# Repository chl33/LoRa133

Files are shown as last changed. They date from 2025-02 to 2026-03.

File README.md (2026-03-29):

# LoRa133

This project is a base station for LoRa-based satellite sensor devices such as [Garden133](https://github.com/chl33/Garden133).  It includes KiCAD board design and C++ firmware.  LoRa133 allows satellite sensor units to communicate using LoRa radio modules and automatically integrate with Home Assistant.  I build the firmware using the [Platformio](https://platformio.org/) build system.

This is a picture of the base station in its project box in [`OpenSCAD/Lora133/`](OpenSCAD/Lora133/).

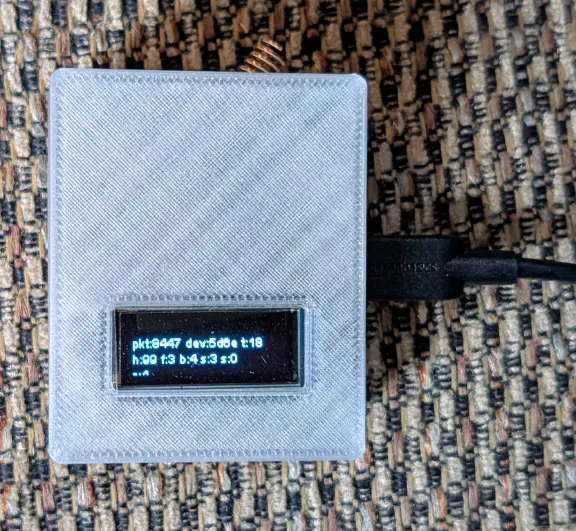
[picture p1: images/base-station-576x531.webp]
Base station


This is the PCBA documented in [`KiCAD/LoRa133/`](KiCAD/LoRa133/).

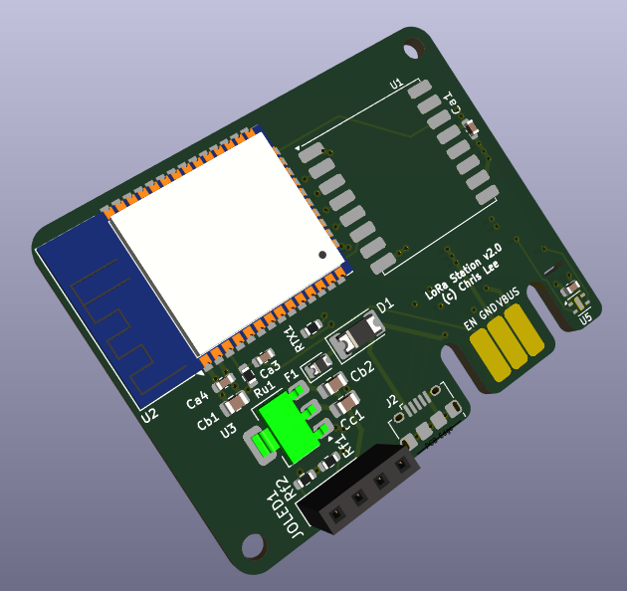
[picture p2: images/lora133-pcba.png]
LoRa133 PCBA


Here is what the web interface (written in Svelte) looks like:

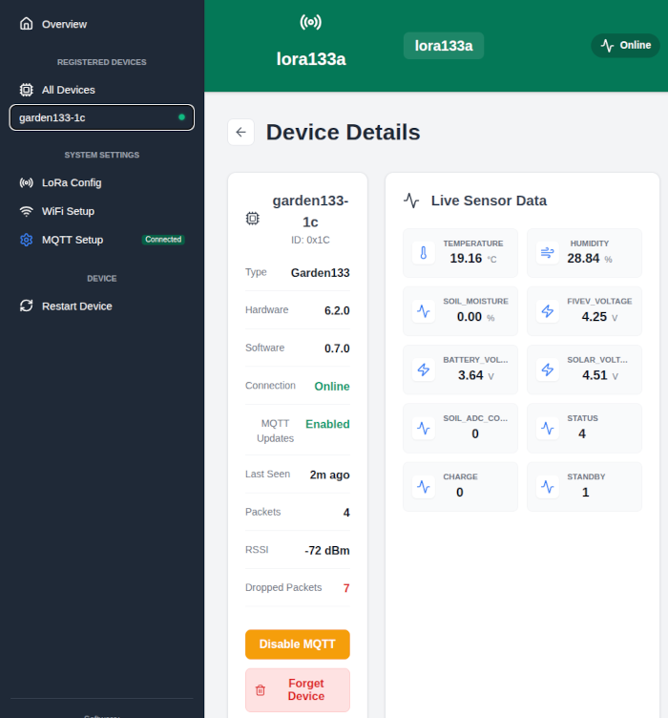
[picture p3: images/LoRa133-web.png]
LoRa133 Web UI


Please see the [Introducing Garden133](https://selectiveappeal.org/posts/garden133/) blog post for more information.

This device uses these libraries:
- [og3](https://github.com/chl33/og3). A basic C++ library for esp development in the Arduino environment.
- [og3x-lora](https://github.com/chl33/og3x-lora). LoRa module support for the og3 library.
- [og3x-satellite](https://github.com/chl33/og3x-satellite). A library that helps build a satellite architecture of a base station and satellite sensors.

## What's New in v0.7.0

*   **Satellite Device Memory**: The bridge now persists its satellite network knowledge across reboots. Restarts no longer result in a blank device list.
*   **Enhanced Visibility**: Real-time RSSI, packet counts, and human-readable "Last Seen" timers added to the web dashboard.
*   **Mobile Optimized**: Fully responsive web interface that fits perfectly on smartphone screens.
*   **og3 v0.6.1 Core**: Modernized backend leveraging the latest declarative dependency and file storage improvements.

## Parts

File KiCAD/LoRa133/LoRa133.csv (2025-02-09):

Source: | /home/chris/KiCad/GardenLee/GardenLee.kicad_sch
Date: | Sat 08 Oct 2022 03:04:13 PM EDT
Tool: | Eeschema 6.0.8-f2edbf62ab~116~ubuntu20.04.1
Generator: | /usr/share/kicad/plugins/bom_csv_grouped_by_value_with_fp.py
Component Count: | 24
Ref | Qnty | Value | Cmp name | Footprint | Description | Vendor
C_3V3_1, | 1 | 100nF | C | Capacitor_SMD:C_0603_1608Metric | Unpolarized capacitor
C_3V3_2, | 1 | 10uF | C | Capacitor_SMD:C_0805_2012Metric | Unpolarized capacitor
C_RST1, | 1 | 100nF | C | Capacitor_SMD:C_0603_1608Metric | Unpolarized capacitor
C_SMTC1, | 1 | 100nF | C | Capacitor_SMD:C_0603_1608Metric | Unpolarized capacitor
CEN1, | 1 | 1uF | C | Capacitor_SMD:C_0603_1608Metric | Unpolarized capacitor
CPI1, | 1 | 10uF | C | Capacitor_SMD:C_0603_1608Metric | Unpolarized capacitor
CPO1, | 1 | 47uF | C | Capacitor_SMD:C_0603_1608Metric | Unpolarized capacitor
DUSB1, | 1 | SS14 | 1N5819 | Diode_SMD:D_2010_5025Metric | 40V 1A Schottky Barrier Rectifier Diode, DO-41
F1, | 1 | 0.5A | Fuse_Small | Diode_SMD:D_0805_2012Metric | Fuse, small symbol
J1, | 1 | USB_B_Micro | USB_B_Micro | Library:USB-micro-aliexpress | USB Micro Type B connector
JCOM1, | 1 | Conn_01x04 | Conn_01x04 | Connector_PinHeader_2.54mm:PinHeader_1x04_P2.54mm_Vertical | Generic connector, single row, 01x04, script generated (kicad-library-utils/schlib/autogen/connector/)
JP1, | 1 | SolderJumper_2_Open | SolderJumper_2_Open | Jumper:SolderJumper-2_P1.3mm_Open_Pad1.0x1.5mm | Solder Jumper, 2-pole, open
Q1, | 1 | UMH3N | UMH3N | Package_TO_SOT_SMD:SOT-363_SC-70-6 | 0.1A Ic, 50V Vce, Dual NPN Input Resistor Transistors, SOT-363
R_IO_1, | 1 | 470 | R | Resistor_SMD:R_0603_1608Metric | Resistor
R_RIO1, | 1 | 12k | R | Resistor_SMD:R_0603_1608Metric | Resistor
REN1, | 1 | 10k | R | Resistor_SMD:R_0603_1608Metric | Resistor
RRX1, | 1 | 470 | R | Resistor_SMD:R_0603_1608Metric | Resistor
RTX1, | 1 | 470 | R | Resistor_SMD:R_0603_1608Metric | Resistor
SW1, | 1 | PTS841 | PTS841 | Library:PTS841
U1, | 1 | RFM95W-915S2 | RFM95W-915S2 | RF_Module:HOPERF_RFM9XW_SMD | Low power long range transceiver module, SPI and parallel interface, 915 MHz, spreading factor 6 to12, bandwith 7.8 to 500kHz, -111 to -148 dBm, SMD-16, DIP-16
U2, | 1 | ESP32-WROOM-32 | ESP32-WROOM-32 | RF_Module:ESP32-WROOM-32 | RF Module, ESP32-D0WDQ6 SoC, Wi-Fi 802.11b/g/n, Bluetooth, BLE, 32-bit, 2.7-3.6V, onboard antenna, SMD
U3, | 1 | AMS1117-3.3 | AMS1117-3.3 | Package_TO_SOT_SMD:SOT-223-3_TabPin2 | 1A Low Dropout regulator, positive, 3.3V fixed output, SOT-223
U4, | 1 | CH340C | CH340C | Package_SO:SOIC-16_3.9x9.9mm_P1.27mm | USB serial converter, UART, SOIC-16
U5, | 1 | SHTC3 | SHTC3 | Sensor_Humidity:Sensirion_DFN-4-1EP_2x2mm_P1mm_EP0.7x1.6mm | Humidity and Temperature Sensor, +/-2%RH, +/-0.2degC, I2C, 1.62-3.6V, DFN-4

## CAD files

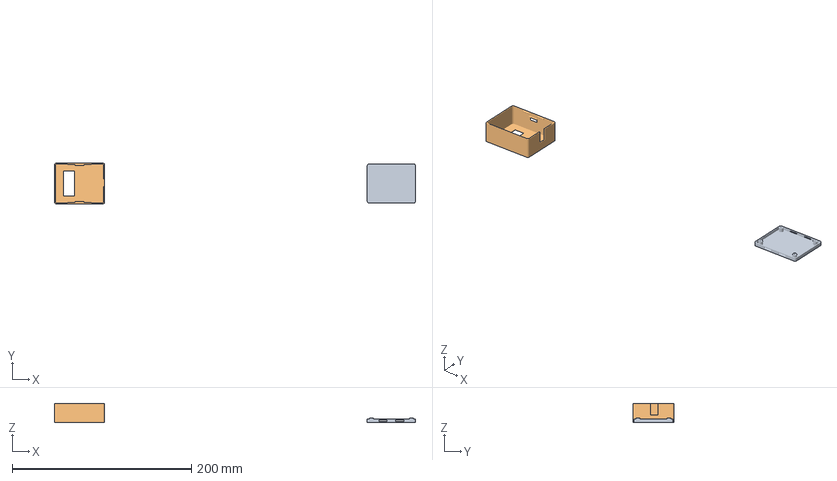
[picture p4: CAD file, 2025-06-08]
OpenSCAD/Lora133/LoRa133.3mf
402.9 x 45.8 x 21.5 mm
box_bottom.stl
box_top.stl

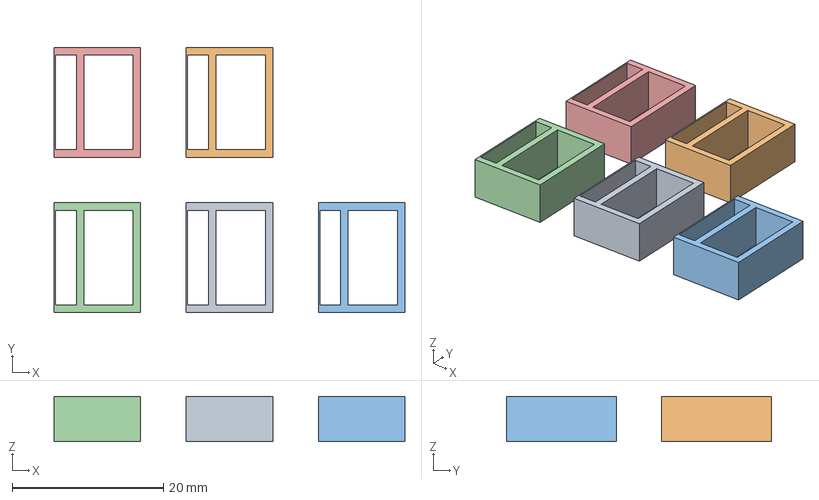
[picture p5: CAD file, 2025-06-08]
OpenSCAD/OLEDSupport/OLEDSupport.3mf
46.4 x 35.0 x 6.00 mm

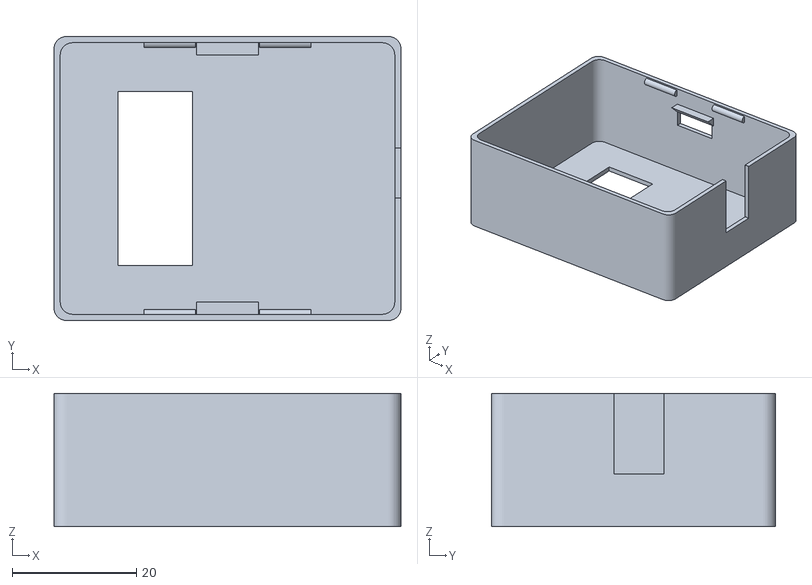
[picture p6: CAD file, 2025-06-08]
OpenSCAD/Lora133/box_top.stl
55.9 x 45.8 x 21.5

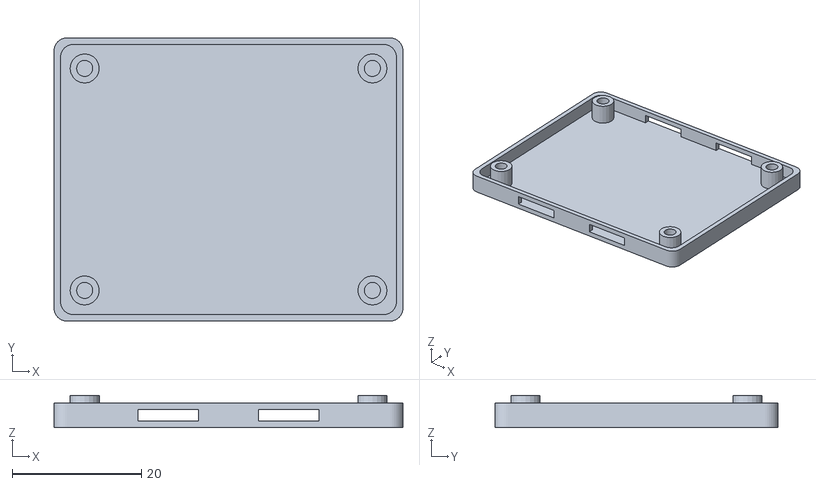
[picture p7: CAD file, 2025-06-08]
OpenSCAD/Lora133/box_bottom.stl
53.9 x 43.8 x 5.01

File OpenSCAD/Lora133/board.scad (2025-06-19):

// Copyright (c) 2025 Chris Lee and contibuters.
// Licensed under the MIT license. See LICENSE file in the project root for details.

include <ProjectBox/project_box.scad>
include <ProjectBox/oled91.scad>

board_thickness = 1.6;
pad_space = 2.54;
// GardenL33: board_dims = [26*pad_space, 15.5*pad_space, board_thickness];
board_dims = [19.5*pad_space, 15.5*pad_space, board_thickness];

module LoRa133_to_oled_frame(z_translate=true) {
  u = pad_space;
  z_offset = z_translate ? 13 : 0;
  translate([u*3-0.5, 0.6, z_offset]) children();
}

module Lora133_board() {
  u = pad_space;

  // Board imported from KiCad (VRML) -> meshlab
   translate([board_dims[0]/2, board_dims[1]/2, board_dims[2]/2]) color("white")
    import(file="LoRa133.stl", convexity=3);

  LoRa133_to_oled_frame() oled91();
}

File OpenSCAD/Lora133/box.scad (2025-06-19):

// Copyright (c) 2025 Chris Lee and contibuters.
// Licensed under the MIT license. See LICENSE file in the project root for details.

include <ProjectBox/project_box.scad>
include <ProjectBox/mounts.scad>
include <board.scad>

ones = [1, 1, 1];

wall_thickness = 1;
gap = 0.2;
corner_radius = 2;
mount_offset = pad_space;

space_above_board = 12.5;
space_below_board = 5;
inner_dims = (board_dims
	      + Z*(space_above_board+space_below_board)
	      + 2*gap*ones);
outer_dims = (inner_dims
	      + 2*ones*wall_thickness
	      + [2, 2, 0] * corner_radius);

module Lora33_box_to_board_frame() {
  in_board_frame(outer_dims, board_dims, 0) children();
}


module in_Lora133_board_frame(board_height=false) {
  zoffset = board_height ? space_below_board + wall_thickness - 1: 0;
  in_board_frame(outer_dims, board_dims, zoffset) children();
}

module Lora133_box(top) {
  wall = wall_thickness;
  u = 2.54;

  difference() {
    union() {
      project_box(outer_dims,
		  wall_thickness=wall_thickness,
		  gap=gap,
		  corner_radius=corner_radius,
		  top=top);
      if (top) {
	// Bumps on top etc.
	// translate(b1o) rounded_box(b1d, corner_radius);
      } else {
	// Stuff to add on bottom.
	in_Lora133_board_frame() translate([0, 0, epsilon]) {
	  at_corners(board_dims, mount_offset)
	    screw_mount(space_below_board, wall, 2.5/2);
	}
      }	
    }
    // Cut outs.
    if (top) {
      // OLED
      Lora33_box_to_board_frame() LoRa133_to_oled_frame(z_translate=false) {
	translate([0, u*2, outer_dims[2] - wall -1]) {
	  cube([12, 28, wall+2]);
	}
      }
      // Hole for antenna.
      translate([outer_dims[0]-wall-1, 18, -1]) cube([wall+2, 8, 14]);
      // Hole for usb
      translate([23, -1, wall + space_below_board + board_thickness-2]) cube([9.5, wall+2, 3.5]);
      
      // Negative space of bumps.
      // translate(b1o+[wall, wall, -epsilon]) rounded_box(b1d-wall*[2, 2, 1], corner_radius);
      // translate(b2o+[wall, wall, -epsilon]) rounded_box(b2d-wall*[2, 2, 1], corner_radius);

    }
  }
}

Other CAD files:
OpenSCAD/Lora133/box_bottom.scad
OpenSCAD/Lora133/box_top.scad
OpenSCAD/Lora133/LoRa133.stl
OpenSCAD/Lora133/Lora133_test.scad
OpenSCAD/Lora133/gui.scad
OpenSCAD/OLEDSupport/OLEDSupport.scad
OpenSCAD/OLEDSupport/OLEDSupport.stl

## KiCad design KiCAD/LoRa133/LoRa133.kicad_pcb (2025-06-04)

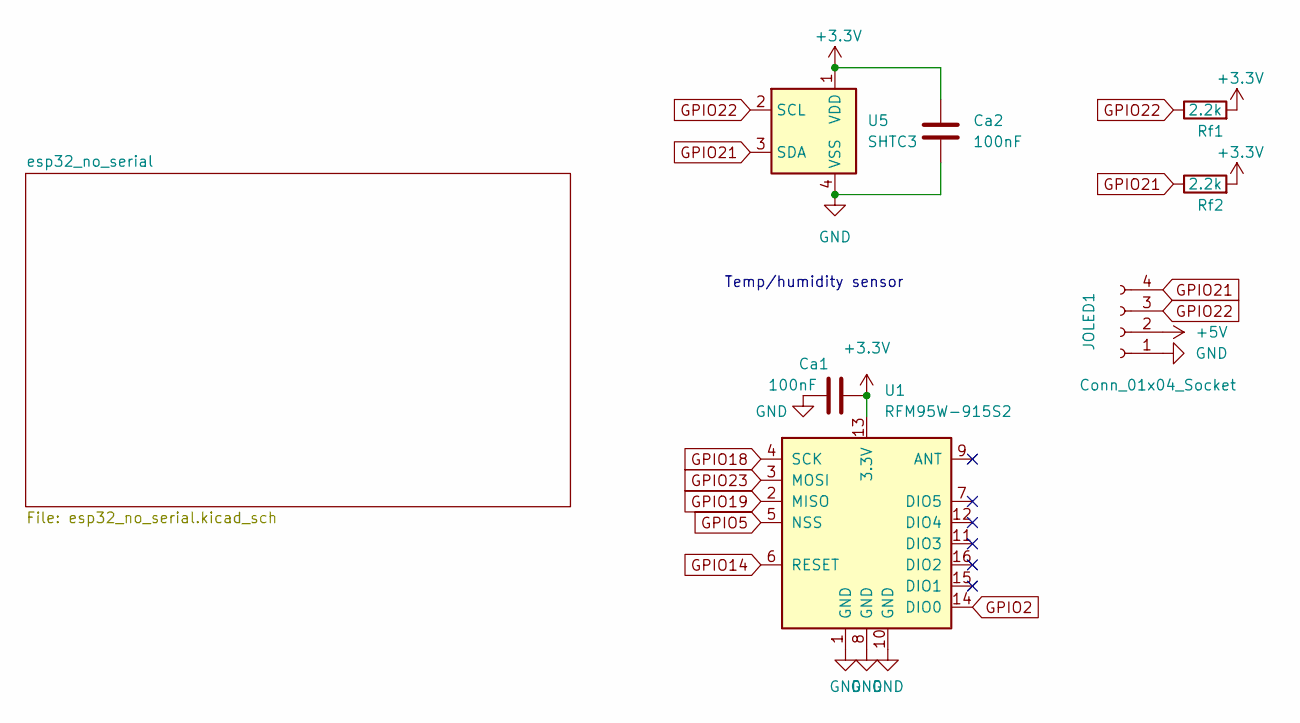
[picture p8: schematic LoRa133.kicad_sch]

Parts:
Ca1, Ca2: 100nF; C_0603_1608Metric
JOLED1: Conn_01x04_Socket; PinSocket_1x04_P2.54mm_Vertical
Rf1, Rf2: 2.2k; R_0603_1608Metric
U1: RFM95W-915S2; HOPERF_RFM9XW_SMD
U5: SHTC3; Sensirion_DFN-4-1EP_2x2mm_P1mm_EP0.7x1.6mm

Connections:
+3.3V: Ca1.2, Ca2.1, Rf1.2, Rf2.2, U1.13 (3.3V), U5.1 (VDD); also elsewhere on the board
+5V: JOLED1.2; also elsewhere on the board
GND: Ca1.1, Ca2.2, JOLED1.1, U1.1 (GND), U1.8 (GND), U1.10 (GND), U5.4 (VSS); also elsewhere on the board
GPIO2: U1.14 (DIO0); also elsewhere on the board
GPIO5: U1.5 (NSS); also elsewhere on the board
GPIO14: U1.6 (RESET); also elsewhere on the board
GPIO18: U1.4 (SCK); also elsewhere on the board
GPIO19: U1.2 (MISO); also elsewhere on the board
GPIO21: JOLED1.4, Rf2.1, U5.3 (SDA); also elsewhere on the board
GPIO22: JOLED1.3, Rf1.1, U5.2 (SCL); also elsewhere on the board
GPIO23: U1.3 (MOSI); also elsewhere on the board

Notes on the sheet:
Temp/humidity sensor

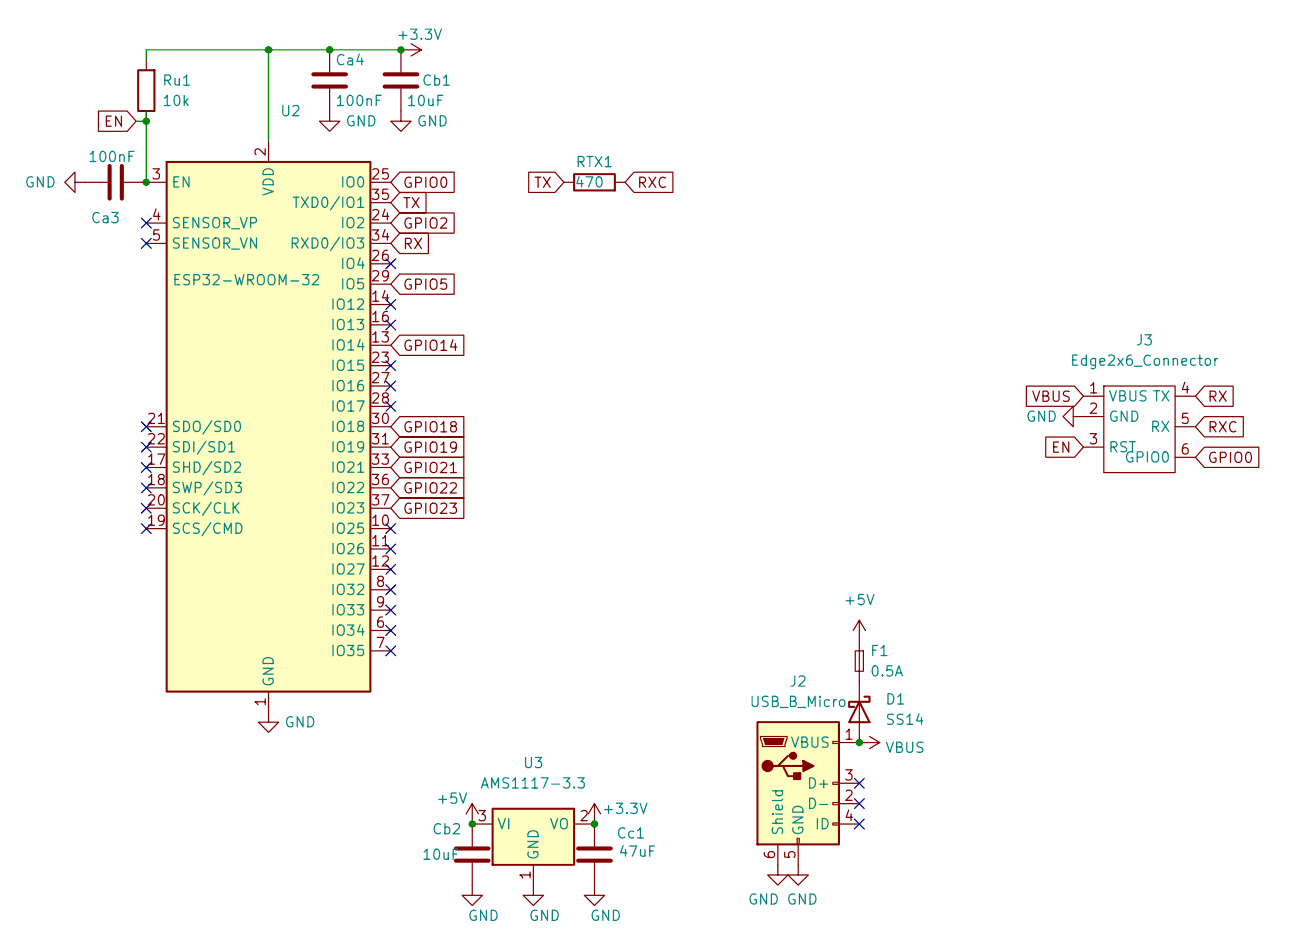
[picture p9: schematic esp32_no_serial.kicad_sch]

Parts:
Ca3, Ca4: 100nF; C_0603_1608Metric
Cb1: 10uF; C_0805_2012Metric
Cb2: 10uF; C_0805_2012Metric_Pad1.18x1.45mm_HandSolder
Cc1: 47uF; C_0805_2012Metric_Pad1.18x1.45mm_HandSolder
D1: SS14; D_2010_5025Metric
F1: 0.5A; D_0805_2012Metric
J2: USB_B_Micro; USB_Micro-B_Amphenol_10118194_Horizontal
J3: Edge2x6_Connector; EdgeConnector_2x3
RTX1: 470; R_0603_1608Metric
Ru1: 10k; R_0603_1608Metric
U2: ESP32-WROOM-32
U3: AMS1117-3.3; SOT-223-3_TabPin2

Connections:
+3.3V: Ca4.1, Cb1.1, Cc1.1, Ru1.2, U2.2 (VDD), U3.2 (VO); also elsewhere on the board
+5V: Cb2.1, F1.1, U3.3 (VI); also elsewhere on the board
EN: Ca3.2, J3.3 (RST), Ru1.1, U2.3 (EN)
GND: Ca3.1, Ca4.2, Cb1.2, Cb2.2, Cc1.2, J2.5 (GND), J2.6 (Shield), J3.2 (GND), U2.1 (GND), U2.15 (GND), U2.38 (GND), U2.39 (GND), U3.1 (GND); also elsewhere on the board
GPIO0: J3.6 (GPIO0), U2.25 (IO0)
GPIO2: U2.24 (IO2); also elsewhere on the board
GPIO5: U2.29 (IO5); also elsewhere on the board
GPIO14: U2.13 (IO14); also elsewhere on the board
GPIO18: U2.30 (IO18); also elsewhere on the board
GPIO19: U2.31 (IO19); also elsewhere on the board
GPIO21: U2.33 (IO21); also elsewhere on the board
GPIO22: U2.36 (IO22); also elsewhere on the board
GPIO23: U2.37 (IO23); also elsewhere on the board
unnamed: D1.1 (K), F1.2
RX: J3.4 (TX), U2.34 (RXD0/IO3)
RXC: J3.5 (RX), RTX1.2
TX: RTX1.1, U2.35 (TXD0/IO1)
VBUS: D1.2 (A), J2.1 (VBUS), J3.1 (VBUS)

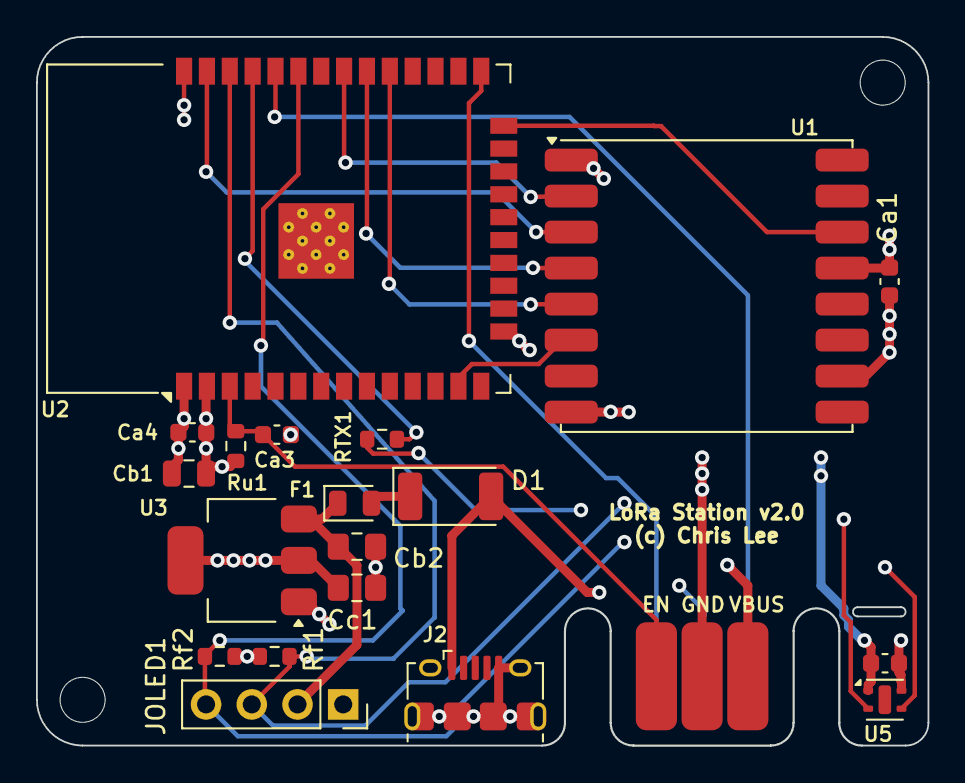
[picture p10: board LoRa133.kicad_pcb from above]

Board: 4 copper layers, 49.5 x 39.4 mm, 20 parts (0 on the bottom side), 18 nets.

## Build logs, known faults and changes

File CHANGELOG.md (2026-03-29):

# Changelog

All notable changes to this project will be documented in this file.

The format is based on [Keep a Changelog](https://keepachangelog.com/en/1.0.0/),
and this project adheres to [Semantic Versioning](https://semver.org/spec/v2.0.0.html).

## [0.7.0] - 2026-03-28

### Added
- **Satellite Persistence**: Implemented full persistence for the satellite network. The bridge now "remembers" all known devices and their sensor configurations across reboots by storing them in flash memory (`/devices.json`).
- **Cold-Start Parsing**: The bridge can now parse sensor data packets immediately after a reboot without waiting for a device description packet, thanks to restored sensor metadata.
- **Dynamic Metadata Sync**: Added support for updating device names, manufacturer IDs, and firmware versions as they arrive in LoRa packets.
- **Enhanced Telemetry**: Added RSSI, packet count, and human-readable "Last Seen" timers to the web interface.
- **Mobile-Responsive UI**: Refactored the Svelte dashboard to support vertical layouts on small screens and improved navigation.
- **Online/Offline Monitoring**: Implemented an automated background task to flag devices as offline and invalidate their sensors in Home Assistant if they miss their check-in window.

### Changed
- **og3 v0.6.1 Migration**: Ported to the latest framework core, utilizing the new `require()` dependency system and `ConfigInterface` file IO helpers.
- **Flash Optimization**: Implemented a 90-second coalescing delay for flash writes to minimize wear during high-traffic startup bursts.
- **JSON API**: Standardized all API keys to `camelCase` for cleaner Svelte integration.

## [0.6.0] - 2026-03-10

### Added
- Initial support for RadioLib and the SX1276 LoRa driver.
- Basic Svelte-based web interface for device monitoring.
- Home Assistant MQTT discovery for satellite sensors.

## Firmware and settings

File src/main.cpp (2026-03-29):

// Copyright (c) 2025 Chris Lee and contibuters.
// Licensed under the MIT license. See LICENSE file in the project root for details.

#include <Arduino.h>
#include <LittleFS.h>
#include <SPI.h>
#include <SSD1306Wire.h>
#include <WiFi.h>
#include <Wire.h>
#include <og3/base-station.h>
#include <og3/constants.h>
#include <og3/ha_app.h>
#include <og3/html_table.h>
#include <og3/lora.h>
#include <og3/oled_wifi_info.h>
#include <og3/packet_reader.h>
#include <og3/satellite.pb.h>
#include <og3/shtc3.h>
#include <og3/text_buffer.h>
#include <og3/web_server.h>
#include <pb_decode.h>

#include <map>

#include "og3/variable.h"
#include "svelteesp32async.h"

#define VERSION "0.7.0"

namespace og3 {

static const char kManufacturer[] = "Chris Lee";
static const char kModel[] = "LoRa133";
static const char kSoftware[] = "LoRa133 v" VERSION;

constexpr uint32_t kCleeOrg = 0xc133;
constexpr uint16_t kDevicePktType = 0xde1c;

#if defined(LOG_UDP) && defined(LOG_UDP_ADDRESS)
constexpr App::LogType kLogType = App::LogType::kUdp;
#else
// constexpr App::LogType kLogType = App::LogType::kNone;  // kSerial
constexpr App::LogType kLogType = App::LogType::kSerial;
#endif

HAApp s_app(HAApp::Options(kManufacturer, kModel,
                           WifiApp::Options()
                               .withSoftwareName(kSoftware)
                               .withDefaultDeviceName("rooml33")
#if defined(LOG_UDP) && defined(LOG_UDP_ADDRESS)
                               .withUdpLogHost(IPAddress(LOG_UDP_ADDRESS))
#endif
                               .withOta(OtaManager::Options(OTA_PASSWORD))
                               .withApp(App::Options().withLogType(kLogType))));

VariableGroup s_vg("status");

static const char kTemperature[] = "temperature";
static const char kHumidity[] = "humidity";

// Id needs to be included in device name.
// Hardware config
// Define the pins used by the transceiver module.
constexpr int kLoraSS = 5;
constexpr int kLoraRst = 14;
constexpr int kLoraDio0 = 2;

Shtc3 s_shtc3(kTemperature, kHumidity, &s_app.module_system(), "temperature", s_vg);

// Have oled display IP address or AP status.
og3::OledWifiInfo wifi_infof(&s_app.tasks());

// Delay between updates of the OLED.
constexpr unsigned kOledSwitchMsec = 10 * kMsecInSec;
OledDisplayRing s_oled(&s_app.module_system(), kSoftware, kOledSwitchMsec, Oled::kTenPt,
                       Oled::Orientation::kDefault);

auto s_lora_options = []() -> LoRaModule::Options {
  LoRaModule::Options opts;
  opts.sync_word = 0xF0;
  opts.enable_crc = true;

  opts.frequency = lora::Frequency::k915MHz;
  opts.spreading_factor = lora::SpreadingFactor::kSF8;
  opts.signal_bandwidth = lora::SignalBandwidth::k125kHz;

  opts.config_options = static_cast<LoRaModule::OptionSelect>(LoRaModule::kOptionSyncWord |
                                                              LoRaModule::kOptionSpreadingFactor |
                                                              LoRaModule::kOptionSignalBandwidth);
  opts.settable_options = static_cast<LoRaModule::OptionSelect>(LoRaModule::kOptionSyncWord |
                                                                LoRaModule::kOptionSpreadingFactor |
                                                                LoRaModule::kOptionSignalBandwidth);

  return opts;
};

// Variables for lora config
VariableGroup s_lora_vg("lora");
// This variable group is for enabling/disabling MQTT for a device.
VariableGroup s_device_cvg("config");
BoolVariable s_device_disable_default("disableDefault", false, "disable by default",
                                      VariableBase::kSettable | VariableBase::kNoPublish,
                                      s_device_cvg);

std::map<uint32_t, std::unique_ptr<base_station::Device>> s_id_to_device;

static const char kDevicesFile[] = "/devices.json";

void save_devices() {
  base_station::Device::saveAll(kDevicesFile, &s_app.config(), s_id_to_device);
}

TaskScheduler s_save_devices_task([]() { save_devices(); }, &s_app.tasks());

// Garden133 at least sends multiple packets to initialize itself.
// Packets are separated by 15 seconds, so wait 30 more seconds before saving
//  each time we get an update.
void request_save_devices() { s_save_devices_task.runIn(30 * og3::kMsecInSec); }

String version_string(const og3_Version& v) {
  if (v.major == 0 && v.minor == 0 && v.patch == 0) {
    return "Unknown";
  }
  char buf[32];
  snprintf(buf, sizeof(buf), "%u.%u.%u", v.major, v.minor, v.patch);
  return String(buf);
}

void load_devices() {
  base_station::Device::loadAll(
      kDevicesFile, &s_app.config(),
      [](uint32_t id, const char* name, uint32_t mfg_id, const char* type, uint32_t timeout_ms,
         const og3_Version& hw_version, const og3_Version& sw_version) {
        auto iter = s_id_to_device.emplace(
            id, new base_station::Device(id, name, mfg_id, type, &s_app.module_system(),
                                         &s_app.ha_discovery(), 0, s_device_cvg));
        if (iter.second) {
          iter.first->second->set_comms_timeout_millis(timeout_ms);
          iter.first->second->set_hardware_version(hw_version);
          iter.first->second->set_software_version(sw_version);
          iter.first->second->setIsOnline(false);
        }
        return iter.first->second.get();
      });
}

LoRaModule s_lora(s_lora_options(), &s_app, s_lora_vg);

// Periodically check if satellite devices have timed out.
PeriodicTaskScheduler s_availability_checker(
    30 * kMsecInSec, 30 * kMsecInSec,
    []() {
      for (auto& iter : s_id_to_device) {
        const auto& device = iter.second;
        if (device->isTimedOut()) {
          device->setIsOnline(false);
        }
      }
    },
    &s_app.tasks());

// Update readings only 1/minute maximum.
constexpr unsigned long kMaxMsecBetweenGardenReadings = 60 * 1000;

uint8_t s_pkt_buffer[1024];

Variable<unsigned> s_pkt_count("pktCount", 0, "", "", 0, s_vg);
Variable<unsigned> s_err_prefix_count("errPrefixCount", 0, "", "", 0, s_vg);
Variable<unsigned> s_err_crc_count("errCrcCount", 0, "", "", 0, s_vg);
Variable<unsigned> s_err_size_count("errSizeCount", 0, "", "", 0, s_vg);
Variable<unsigned> s_err_version_count("errVersionCount", 0, "", "", 0, s_vg);

const char* str(og3_Sensor_Type val) {
  switch (val) {
    case og3_Sensor_Type_TYPE_UNSPECIFIED:
      return nullptr;
    case og3_Sensor_Type_TYPE_VOLTAGE:
      return ha::device_class::sensor::kVoltage;
    case og3_Sensor_Type_TYPE_TEMPERATURE:
      return ha::device_class::sensor::kTemperature;
    case og3_Sensor_Type_TYPE_HUMIDITY:
      return ha::device_class::sensor::kHumidity;
    case og3_Sensor_Type_TYPE_MOISTURE:
      return ha::device_class::sensor::kMoisture;
    default:
      return "???";
  }
}

unsigned decimals(og3_Sensor_Type val) {
  switch (val) {
    case og3_Sensor_Type_TYPE_UNSPECIFIED:
      return 0;
    case og3_Sensor_Type_TYPE_VOLTAGE:
      return 2;
    case og3_Sensor_Type_TYPE_TEMPERATURE:
    case og3_Sensor_Type_TYPE_HUMIDITY:
    case og3_Sensor_Type_TYPE_MOISTURE:
      return 1;
    default:
      return 0;
  }
}

void parse_device_packet(uint16_t seq_id, const uint8_t* msg, std::size_t msg_size) {
  pb_istream_t istream = pb_istream_from_buffer(msg, msg_size);
  og3_Packet packet;
  if (!pb_decode(&istream, &og3_Packet_msg, &packet)) {
    s_app.log().log("Proto decode of device packet failed.");
    return;
  }

  s_app.log().debugf("Parsed device packet (seq_id:%u).", seq_id);

  TextBuffer<64> text;
  text.addf("pkt:%0u dev:%x", seq_id, packet.device_id);

  auto dev_iter = s_id_to_device.find(packet.device_id);
  base_station::Device* pdevice = nullptr;
  if (dev_iter != s_id_to_device.end()) {
    pdevice = dev_iter->second.get();
    pdevice->got_packet(seq_id, og3::s_lora.last_rssi());
    s_app.log().logf("Known device id:%u %s'%s' (%s) (seq_id=%u, dropped=%u).", packet.device_id,
                     packet.has_device ? "(dev info sent) " : "", pdevice->cname(),
                     packet.device.device_type, seq_id, pdevice->dropped_packets());
  } else {
    if (!packet.has_device) {
      s_app.log().logf("No known device with id=%u (seq_id=%u).", packet.device_id, seq_id);
      return;
    }
    const auto& device = packet.device;
    s_app.log().logf("Device: id:0x%X mfg:0x%X '%s' (%s)", device.id, device.manufacturer,
                     device.name, device.device_type);
    if (device.has_hardware_version) {
      const auto& ver = device.hardware_version;
      s_app.log().logf(" hw: %u.%u.%u", ver.major, ver.minor, ver.patch);
    }
    if (device.has_software_version) {
      const auto& ver = device.software_version;
      s_app.log().logf(" sw: %u.%u.%u", ver.major, ver.minor, ver.patch);
    }
    auto iter = s_id_to_device.emplace(
        packet.device_id,
        new base_station::Device(packet.device_id, device.name, device.manufacturer,
                                 device.device_type, &s_app.module_system(), &s_app.ha_discovery(),
                                 seq_id, s_device_cvg));
    pdevice = iter.first->second.get();
    pdevice->set_disabled(s_device_disable_default.value());
    request_save_devices();
  }

  if (packet.has_device) {
    bool changed = false;
    if (strlen(packet.device.name) > 0 && pdevice->name() != packet.device.name) {
      pdevice->set_name(packet.device.name);
      changed = true;
    }
    if (packet.device.manufacturer > 0 && pdevice->mfg_id() != packet.device.manufacturer) {
      pdevice->set_mfg_id(packet.device.manufacturer);
      changed = true;
    }
    if (strlen(packet.device.device_type) > 0 &&
        pdevice->device_type() != packet.device.device_type) {
      pdevice->set_device_type(packet.device.device_type);
      changed = true;
    }
    if (packet.device.timeout_secs > 0) {
      const uint32_t new_timeout_ms = packet.device.timeout_secs * 1000;
      if (new_timeout_ms != pdevice->comms_timeout_millis()) {
        pdevice->set_comms_timeout_millis(new_timeout_ms);
        changed = true;
      }
    }
    if (packet.device.has_hardware_version) {
      const auto& v = packet.device.hardware_version;
      const auto& cur = pdevice->hardware_version();
      if (v.major != cur.major || v.minor != cur.minor || v.patch != cur.patch) {
        pdevice->set_hardware_version(v);
        changed = true;
      }
    }
    if (packet.device.has_software_version) {
      const auto& v = packet.device.software_version;
      const auto& cur = pdevice->software_version();
      if (v.major != cur.major || v.minor != cur.minor || v.patch != cur.patch) {
        pdevice->set_software_version(v);
        changed = true;
      }
    }
    if (changed) {
      request_save_devices();
    }
  }

  s_pkt_count = s_pkt_count.value() + 1;

  // Update MQTT availability message if it applies.
  pdevice->setIsOnline(true);

  // Set all device sensor readings to "Failed" so we don't re-use values not included in
  //  this packet.
  pdevice->setAllSensorReadingsFailed();

  // Read the sensor entries.
  for (unsigned idx_sensor = 0; idx_sensor < packet.sensor_count; idx_sensor++) {
    const auto& sensor = packet.sensor[idx_sensor];
    if (sensor.type == og3_Sensor_Type_TYPE_INT_NUMBER) {
      // IntSensor
      auto* psensor = pdevice->int_sensor(sensor.id);
      if (!psensor) {
        pdevice->add_int_sensor(sensor.id, sensor.name, nullptr, sensor.units, pdevice,
                                sensor.state_class);
        request_save_devices();
        s_app.log().logf(
            " - set int sensor:%u (%s%s) in device:%u", sensor.id, sensor.name,
            (sensor.state_class == og3_Sensor_StateClass_STATE_CLASS_MEASUREMENT ? " measurement"
                                                                                 : ""),
            packet.device_id);
      } else {
        // TODO: update sensor entry if anything changed.
        s_app.log().logf(
            " - sensor info update :%u (%s %s%s) in device:%x", sensor.id, sensor.name,
            sensor.units,
            (sensor.state_class == og3_Sensor_StateClass_STATE_CLASS_MEASUREMENT ? " measurement"
                                                                                 : ""),
            packet.device_id);
      }
    } else {
      // FloatSensor
      base_station::FloatSensor* psensor = pdevice->float_sensor(sensor.id);
      if (!psensor) {
        pdevice->add_float_sensor(sensor.id, sensor.name, str(sensor.type), sensor.units,
                                  decimals(sensor.type), pdevice, sensor.state_class);
        request_save_devices();
        s_app.log().logf(
            " - set sensor:%u (%s %s%s) in device:%x", sensor.id, sensor.name, sensor.units,
            (sensor.state_class == og3_Sensor_StateClass_STATE_CLASS_MEASUREMENT ? " measurement"
                                                                                 : ""),
            packet.device_id);
      } else {
        // TODO: update sensor entry if anything changed.
        s_app.log().logf(
            " - sensor info update :%u (%s %s%s) in device:%x", sensor.id, sensor.name,
            sensor.units,
            (sensor.state_class == og3_Sensor_StateClass_STATE_CLASS_MEASUREMENT ? " measurement"
                                                                                 : ""),
            packet.device_id);
      }
    }
  }

  // Read the float-sensor readings.
  for (unsigned idx_reading = 0; idx_reading < packet.reading_count; idx_reading++) {
    const auto& reading = packet.reading[idx_reading];
    base_station::FloatSensor* psensor = pdevice->float_sensor(reading.sensor_id);

    if (!psensor) {
      s_app.log().logf("No sensor id:%u known for device:%u.", reading.sensor_id, packet.device_id);
      continue;
    }
    psensor->value() = reading.value;
    s_app.log().logf(" %u: %s ->  %.2f", reading.sensor_id, psensor->cname(), reading.value);
    const char nc = psensor->cname()[0] ? psensor->cname()[0] : ' ';
    text.addf(" %c:%.0f", nc, reading.value);
  }
  for (unsigned idx_reading = 0; idx_reading < packet.i_reading_count; idx_reading++) {
    const auto& reading = packet.i_reading[idx_reading];
    base_station::IntSensor* psensor = pdevice->int_sensor(reading.sensor_id);

    if (!psensor) {
      s_app.log().logf("No sensor id:%u known for device:%u.", reading.sensor_id, packet.device_id);
      continue;
    }
    psensor->value() = reading.value;
    s_app.log().logf(" %u: %s ->  %d", reading.sensor_id, psensor->cname(), reading.value);
    const char nc = psensor->cname()[0] ? psensor->cname()[0] : ' ';
    text.addf(" %c:%d", nc, reading.value);
  }
  if (!pdevice->is_disabled()) {
    s_app.mqttSend(pdevice->vg());
  }
  text.split(22);
  s_oled.display(text.text());
}

// Global variable for html, so asyncwebserver can send data in the background (single client)
String s_html;

WebButton s_button_wifi_config = s_app.createWifiConfigButton();
WebButton s_button_mqtt_config = s_app.createMqttConfigButton();
WebButton s_button_app_status = s_app.createAppStatusButton();
WebButton s_button_restart = s_app.createRestartButton();

static String s_body;

NetHandlerStatus apiGetWifi(NetRequest* request, NetResponse* response) {
  JsonDocument jsondoc;
  JsonObject json = jsondoc.to<JsonObject>();
  const auto& wifi = s_app.wifi_manager();
  json["board"] = wifi.board();
  json["wifiPassword"] = wifi.wifiPassword();
  json["essId"] = wifi.essId();
  json["ipAddr"] = wifi.ipAddr();
  s_body.clear();
  serializeJson(jsondoc, s_body);
  response->send(200, "application/json", s_body.c_str());
  NET_REPLY(request, ESP_OK);
}

NetHandlerStatus putWifiConfig(NetRequest* request, NetResponse* response, JsonVariant& jsonIn) {
  if (!jsonIn.is<JsonObject>()) {
    response->send(500, "text/plain", "not a json object");
    NET_REPLY(request, ESP_FAIL);
  }
  JsonObject obj = jsonIn.as<JsonObject>();
  s_app.wifi_manager().variables().updateFromJson(obj);
  s_app.config().write_config(s_app.wifi_manager().variables());
  response->send(200, "text/plain", "ok");
  NET_REPLY(request, ESP_OK);
}

NetHandlerStatus apiGetMqtt(NetRequest* request, NetResponse* response) {
  JsonDocument jsondoc;
  JsonObject json = jsondoc.to<JsonObject>();
  const auto& mqtt = s_app.mqtt_manager();
  json["enabled"] = mqtt.isEnabled();
  json["hostAddr"] = mqtt.hostAddr();
  json["authPassword"] = mqtt.authPassword();
  json["authUser"] = mqtt.authUser();
  s_body.clear();
  serializeJson(jsondoc, s_body);
  response->send(200, "application/json", s_body.c_str());
  NET_REPLY(request, ESP_OK);
}

NetHandlerStatus putMqttConfig(NetRequest* request, NetResponse* response, JsonVariant& jsonIn) {
  if (!jsonIn.is<JsonObject>()) {
    response->send(500, "text/plain", "not a json object");
    NET_REPLY(request, ESP_FAIL);
  }
  JsonObject obj = jsonIn.as<JsonObject>();
  s_app.mqtt_manager().variables().updateFromJson(obj);
  s_app.config().write_config(s_app.mqtt_manager().variables());
  response->send(200, "text/plain", "ok");
  NET_REPLY(request, ESP_OK);
}

NetHandlerStatus apiGetLora(NetRequest* request, NetResponse* response) {
  JsonDocument jsondoc;
  JsonObject json = jsondoc.to<JsonObject>();
  s_lora_vg.toJson(json, 0);
  s_body.clear();
  serializeJson(jsondoc, s_body);
  response->send(200, "application/json", s_body.c_str());
  NET_REPLY(request, ESP_OK);
}

NetHandlerStatus putLoraConfig(NetRequest* request, NetResponse* response, JsonVariant& jsonIn) {
  if (!jsonIn.is<JsonObject>()) {
    response->send(500, "text/plain", "not a json object");
    NET_REPLY(request, ESP_FAIL);
  }
  JsonObject obj = jsonIn.as<JsonObject>();
  s_lora_vg.updateFromJson(obj);
  s_app.config().write_config(s_lora_vg);
  response->send(200, "text/plain", "ok");
  NET_REPLY(request, ESP_OK);
}

NetHandlerStatus apiGetStatus(NetRequest* request, NetResponse* response) {
  JsonDocument jsondoc;
  JsonObject json = jsondoc.to<JsonObject>();
  s_app.app_status().variables().toJson(json, 0);
  s_vg.toJson(json, 0);
  json["mqttConnected"] = s_app.mqtt_manager().isConnected();
  s_body.clear();
  serializeJson(jsondoc, s_body);
  response->send(200, "application/json", s_body.c_str());
  NET_REPLY(request, ESP_OK);
}

NetHandlerStatus apiGetDevices(NetRequest* request, NetResponse* response) {
  JsonDocument jsondoc;
  JsonArray arr = jsondoc.to<JsonArray>();
  for (auto& iter : s_id_to_device) {
    const auto& device = iter.second;
    JsonObject obj = arr.add<JsonObject>();
    obj["id"] = iter.first;
    obj["name"] = device->cname();
    obj["type"] = device->cdevice_type();
    obj["disabled"] = device->is_disabled();
    obj["isOnline"] = device->is_online();
    obj["packetCount"] = device->packet_count();
    obj["rssi"] = device->rssi();
    obj["lastSeenSecs"] = device->last_packet_millis() > 0
                              ? static_cast<long>(millis() - device->last_packet_millis()) / 1000
                              : -1;
    obj["droppedPackets"] = device->dropped_packets();
    obj["swVersion"] = version_string(device->software_version());
  }
  s_body.clear();
  serializeJson(jsondoc, s_body);
  response->send(200, "application/json", s_body.c_str());
  NET_REPLY(request, ESP_OK);
}

NetHandlerStatus apiPostDeviceForget(NetRequest* request, NetResponse* response) {
  if (!request->hasParam("id")) {
    response->send(400, "text/plain", "missing id");
    NET_REPLY(request, ESP_FAIL);
  }
  uint32_t id = strtoul(request->getParam("id")->value().c_str(), nullptr, 0);
  auto iter = s_id_to_device.find(id);
  if (iter == s_id_to_device.end()) {
    response->send(404, "text/plain", "not found");
    NET_REPLY(request, ESP_FAIL);
  }
  s_id_to_device.erase(iter);
  request_save_devices();
  response->send(200, "application/json", "{\"isOk\":true}");
  NET_REPLY(request, ESP_OK);
}
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
void loop() {
  og3::s_app.loop();

  if (!og3::s_lora.is_ok()) {
    return;
  }

  // Try to parse a packet.
  int packetSize = og3::s_lora.poll_packet(og3::s_pkt_buffer, sizeof(og3::s_pkt_buffer));
  if (packetSize > 0) {
    // Received a packet.
    og3::s_app.log().logf("Got packet: %d bytes (RSSI: %.1f, SNR: %.1f).", packetSize,
                          og3::s_lora.last_rssi(), og3::s_lora.last_snr());
    og3::process_lora_packets(og3::s_pkt_buffer, packetSize);
  }
}

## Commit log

2025-02-09 initial version -- WIP
    [LoRa133.csv, LoRa133.kicad_pcb, LoRa133.kicad_sch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]
2025-02-09 Start of "satellite" sensor/device support.
2025-02-10 Track dropped packets and RSSI for each satellite device.
2025-02-17 Lots of progress
    - Updated PCB design
    - Added draft of EBox design, and support for OLED.
    - OLED display support
    [LoRa133.3mf, LoRa133.kicad_pcb, LoRa133.stl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]
2025-02-17 Box update: taller, more antenna space
    [box.scad, box_bottom.stl, box_top.stl]
2025-02-17 Add support for int-sensor, moisture raw-value
2025-02-19 update README, include device_id as part of device-name
    [LoRa133.3mf]
2025-02-22 Support HA discovery for satellite sensors
    - Many improvements
    - Depend on newer versions of og3 libraries
    - Use CRC checks on LoRa packets
2025-03-23 Add device name in ha-discovery topic, to avoid conflicts
    [main.cpp]
2025-05-20 Improvements
    - Trying to add RSSI and dropped packets variable for each device
    - Track each kind of packet-parsing error
    - Upgrade og3 version to check packet CRCs
    [main.cpp]
2025-06-04 Fix entry-name for device rssi and dropped packets
2025-06-04 KiCAD: updated KiCAD version, page size -> US Letter
    [LoRa133.kicad_pcb]
2025-06-05 Send MQTT packet every 5 minutes. Actually read the SHTC3 sensor.
2025-06-08 Protocol update, use updated og3x-lora
    - LoRa now configurable via web interface
    - Use og3x-satellite for protobuf messages
    - Update to KiCAD
    - OpenSCAD: base-station box: position hole for antenna if it is orthogonal to the board
    edge
    - Add IP address, temp+humidity to OLED display ring.
    [LoRa133.3mf, OLEDSupport.3mf, box.scad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]
2025-06-13 Add a web page which allows disabling MQTT for a device.
2025-06-14 Support sensor state_class for HA long-term statistics
2025-06-14 KiCAD cache update
2025-06-19 base station update (#1)
    - Base station library moved to og3x-satellite
    - Don't send a device class when sensor type is unspecified
    [Lora133_test.scad, OLEDSupport.scad, board.scad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]
2025-07-05 version 0.4.3 (#2)
    - fix lora-config web page
    - option to disable new devices by default (useful for dev)
    - remove obsolete library
    [main.cpp]
2025-07-19 version 0.5.0 (#4)
    - Use updated og3x-satellite library for protocol update
    - Use device name directly from satellite protobuf as HA discovery device name
    - Use new device_type as model in HA device
2025-08-08 version 0.1.5: set readings failed before parsing LoRa packet (#6)
    This keeps value not in LoRa packets out of MQTT messages.
    [main.cpp]
2026-03-29 version 0.7.0 (#7)
    ### Added
    - **Satellite Persistence**: Implemented full persistence for the satellite network. The bridge now "remembers" all known devices and their sensor configurations across reboots by storing them in flash memory (`/devices.json`).
    - **Cold-Start Parsing**: The bridge can now parse sensor data packets immediately after a reboot without waiting for a device description packet, thanks to restored sensor metadata.
    - **Dynamic Metadata Sync**: Added support for updating device names, manufacturer IDs, and firmware versions as they arrive in LoRa packets.
    - **Enhanced Telemetry**: Added RSSI, packet count, and human-readable "Last Seen" timers to the web interface.
    - **Mo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
    [main.cpp]
